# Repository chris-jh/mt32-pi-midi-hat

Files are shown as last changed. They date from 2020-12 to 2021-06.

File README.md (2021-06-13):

# mt32-pi-midi-hat
A Raspberry Pi Midi Hat for the project mt32-pi by Dale Whinham (https://github.com/dwhinham/mt32-pi).

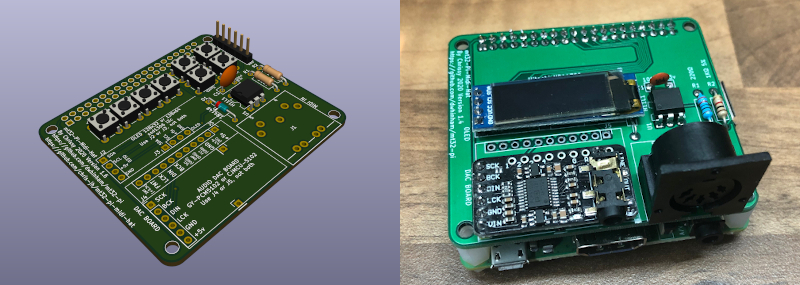
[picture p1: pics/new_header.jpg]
PCB


This PCB is designed from the schematic available from the above project.

The Gerbers have been created from the recommendations at JLCPCB.

(https://support.jlcpcb.com/article/102-kicad-515---generating-gerber-and-drill-files)

You may need to re-generate for your chosen PCB Manufacturer

Version 1.7.2 Copyright 2021 Chrissy

* Moved a trace that was too close to the mounting screw hole. Could cause a short if over tighten to expose the trace. (see https://github.com/chris-jh/mt32-pi-midi-hat/issues/3)

Version 1.7.1 Copyright 2021 Chrissy

* Moved the Midi-Din slightly

Version 1.7 Copyright 2021 Chrissy

* Fixed Silk Screen error on buttons for mt32/sf and Synth, they were opposite

Version 1.6 Copyright 2021 Chrissy

* Removed Hitachi HD44780 4 bit connection, use i2c version
* Added control pins and buttons, see (https://github.com/dwhinham/mt32-pi/wiki/Control-surface)

## Audio DAC's

I designed this Hat to accommodate 2 different PCM5102 DAC boards that are available from Amazon or eBay.

***GY-PCM5102***

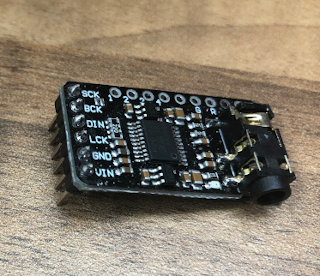
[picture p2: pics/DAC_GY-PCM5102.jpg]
DAC_GY


***CJMCU-5102***

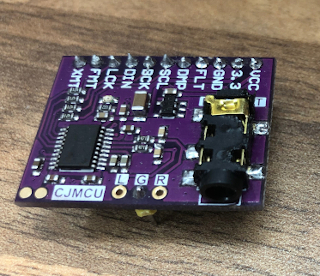
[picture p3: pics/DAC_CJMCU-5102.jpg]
DAC_CJMCU


Currently the GY-PCM5102 version seems to be the most popular on Amazon and eBay, just search for PCM5102.

## Screen's

**SSD1306 OLED**

The Hat can take either the 128x32 SSD1306 OLED, or the 128x64 SSD1306 OLED

***SSD1306 OLED 128x32***

OLED_32

***SSD1306 OLED 128x64***

OLED_64

Again both screens are available from Amazon or eBay.

The 128x64 OLED connects on the board at this position here.

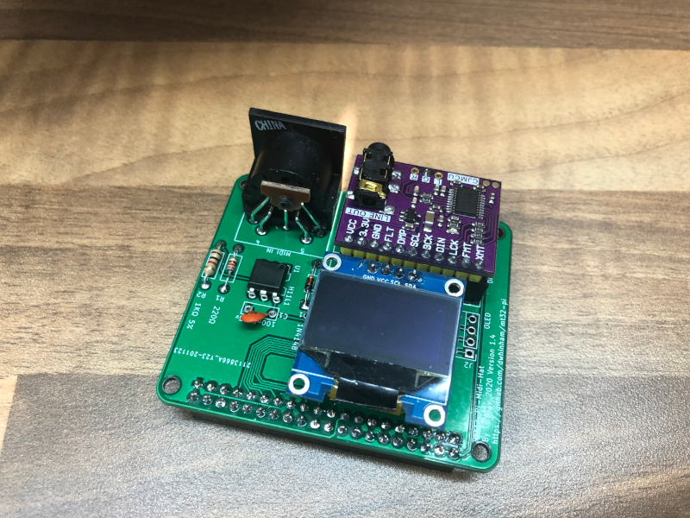
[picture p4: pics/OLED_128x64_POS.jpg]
OLED_64_POS


You will need to put some none conductive material under the OLED,<br>so it does not short agains the Pins of the Raspberry Pi.

When you buy your screen, make sure the PIN order is as follow's (left to right, looking down on the screen):-

| 1 | 2 | 3 | 4 |
|---|---|---|---|
|GND|VCC|SCL|SDA|

You can see this in the photo above.

Some SSD1306 OLED's have Pins 1 and 2 swapped, which will be bad. So please double check.

***Hitachi HD44780***

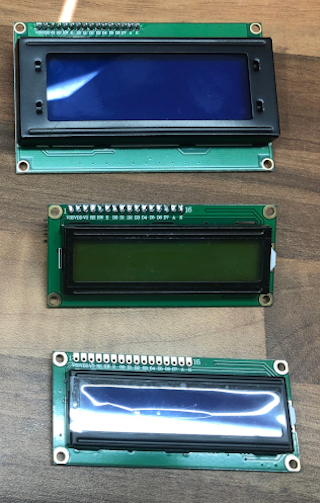
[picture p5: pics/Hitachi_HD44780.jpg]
[](pics/Hitachi_HD44780.jpg)

There are two versions of this screen, one that communicates via the i2c (like the above OLEDS) or a direct connection.

I have removed the direction connection from v1.6 to give enough room to fit the control buttons.

Use the i2c version only and you will need to connect the screen to one of the OLED connections J2 or J3 on the PCB.

The Hitachi screen can also come in different sizes, ideally you want one that is 20 characters in length and either 2 or 4 lines.

<br>

### Configuration

Please see the main mt32-pi Project (https://github.com/dwhinham/mt32-pi) on how to configure and use your screen and DAC.

### BOM

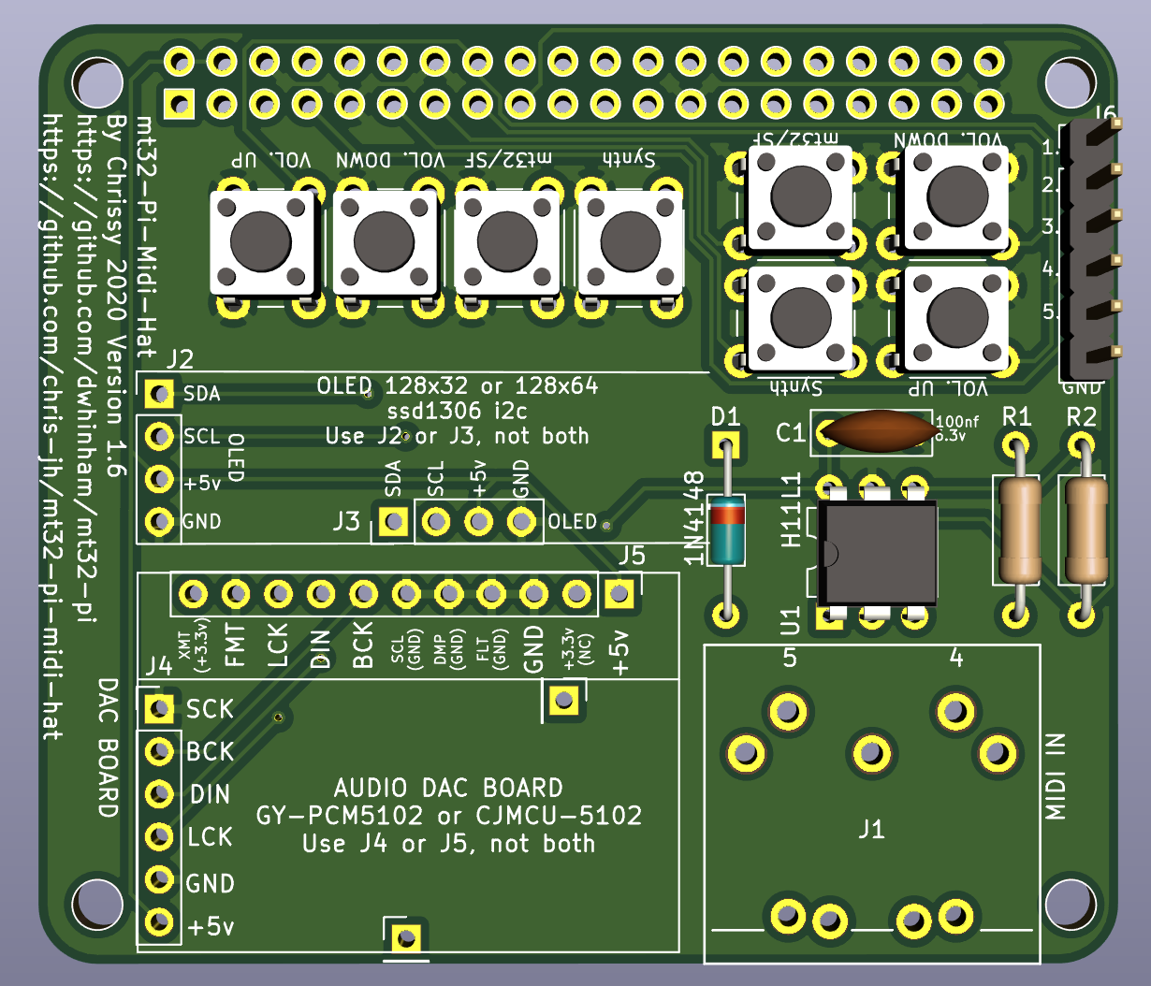
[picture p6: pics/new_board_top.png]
PCB_TOP


| Reference | Value | Quantity | URL |
|---|---|---|-----|
| C1 | 100nf | 1 | https://www.mouser.co.uk/ProductDetail/Murata-Electronics/RCER71E104K0K1H03B?qs=Ey7%2FXF42M3ci4g3t0g7SIw%3D%3D |
| R1 | 220Ω | 1 | https://www.mouser.co.uk/ProductDetail/Vishay-Beyschlag/MBB02070C2200FCT00?qs=PwR17mNzlcOWyOoLtTQfsw%3D%3D |
| R2 | 1KΩ 5% | 1 | https://www.mouser.co.uk/ProductDetail/Vishay-Dale/CCF071K00JKE36?qs=NQWA6AwZmkMdaaeOGvuguw%3D%3D |
| D1 | 1N4148 | 1 | https://www.mouser.co.uk/ProductDetail/ON-Semiconductor-Fairchild/1N4148?qs=i4Fj9T%2FoRm8RMUhj5DeFQg%3D%3D |
| U1 | H11L1 | 1 | https://www.mouser.co.uk/ProductDetail/ON-Semiconductor-Fairchild/H11L1M?qs=P36CEcFBmYxn5ViwkIckpw%3D%3D |
| J1 | DIN-5 | 1 | https://www.mouser.co.uk/ProductDetail/490-SDS-50J |
| J2 or J3 | SSD1306 OLED | 1 | Amazon or eBay |
| J4 or J5 | DAC GY-PCM5102<br>or<br>CJMCU-5102  | 1 | Amazon or eBay |
| J6 | External Button Pin Header 1x6 | 1 | Amazon or eBay |
| SW1,2,3,4 | Tact Switch 6x6mm | 4 | Amazon or eBay |
| Pi | Header| 1 | https://www.mouser.co.uk/ProductDetail/Samtec/SSQ-120-23-G-D?qs=rU5fayqh%252BE1BMVd%252BDZONqg%3D%3D |

You may want to get some general Pin Headers 2.54mm, only 1 extra pin is used to stabilise the DAC's for when pushing in the headphone jack.

[**THT Interactive BOM**][IBOMTHT1_6]

## !!!!! WARNING !!!!!

Use at your own risk. I accept no responsibility if this damages any of your equipment.

[IBOMTHT1_6]: http://htmlpreview.github.io/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

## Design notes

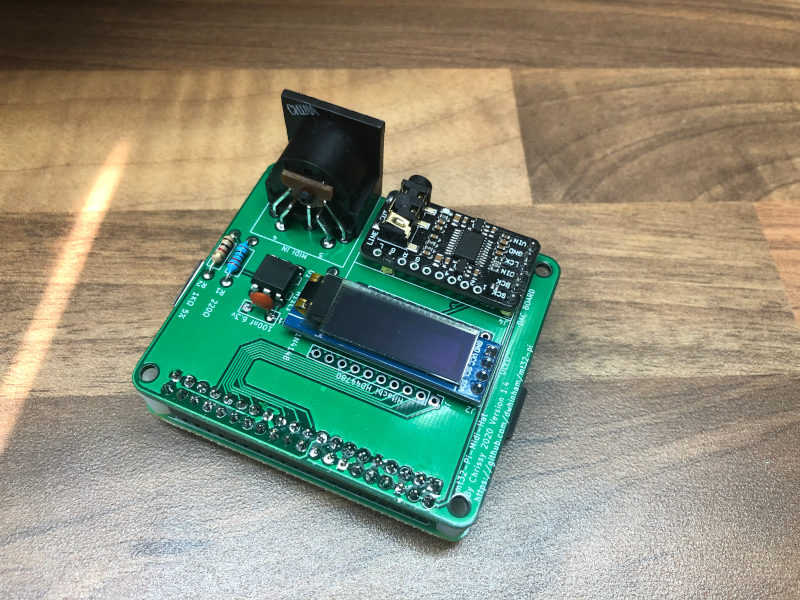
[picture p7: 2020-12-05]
pics/board_back.jpg

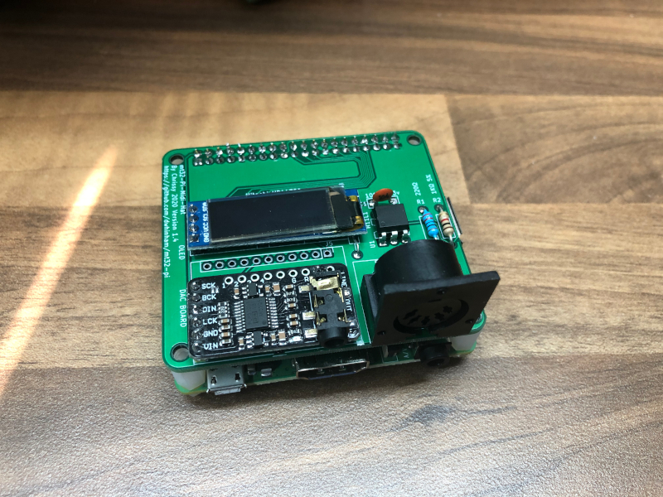
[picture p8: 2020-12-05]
pics/board_front.jpg

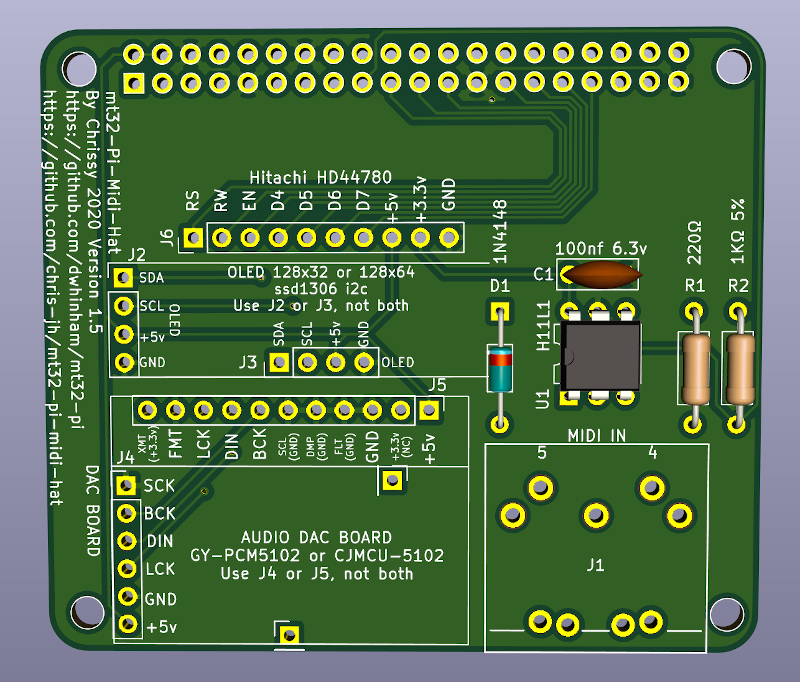
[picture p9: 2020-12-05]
pics/board_top.jpg

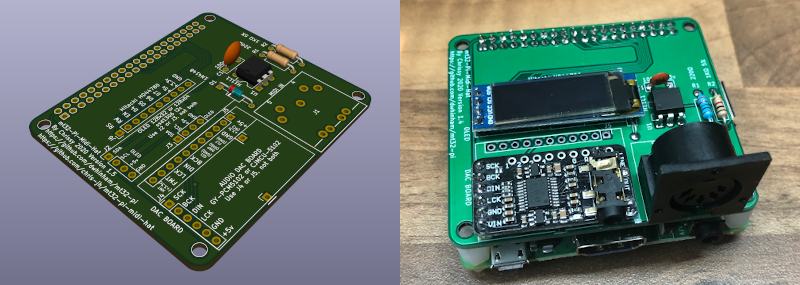
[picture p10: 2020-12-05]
pics/header.jpg

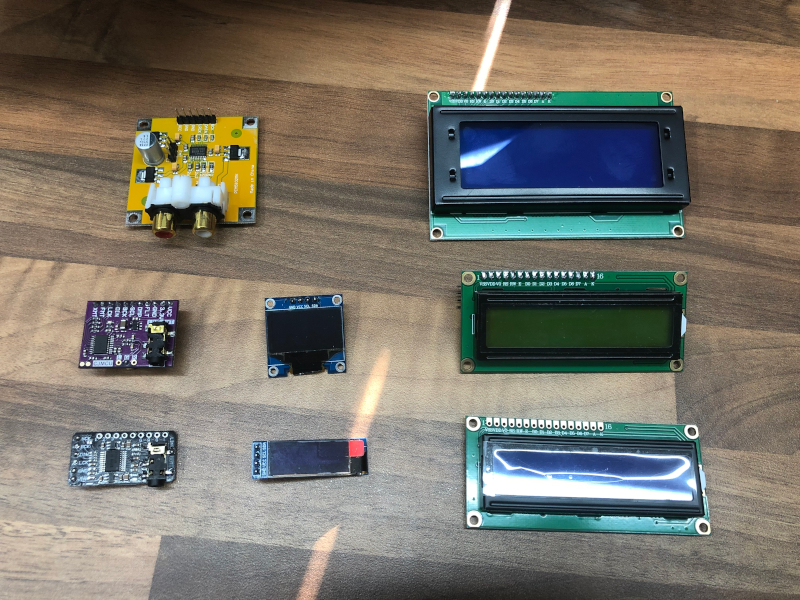
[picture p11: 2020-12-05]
pics/dacs_screens.jpg

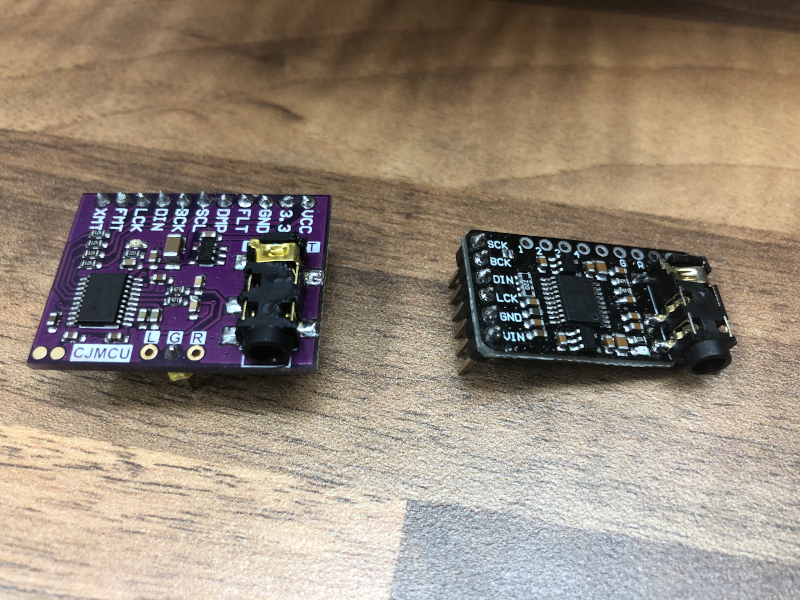
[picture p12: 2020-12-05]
pics/PM5102_DACS.jpg

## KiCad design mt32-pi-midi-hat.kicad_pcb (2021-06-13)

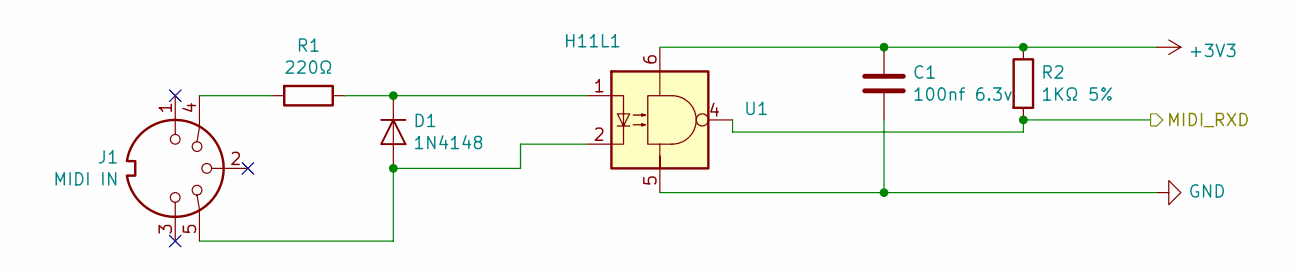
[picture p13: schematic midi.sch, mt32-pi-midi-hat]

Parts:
C1: 100nf 6.3v; C_Disc_D7.0mm_W2.5mm_P5.00mm
D1: 1N4148; D_DO-35_SOD27_P10.16mm_Horizontal
J1: MIDI IN; DIN-5-Variable
R1: 220Ω; R_Axial_DIN0207_L6.3mm_D2.5mm_P10.16mm_Horizontal
R2: 1KΩ 5%; R_Axial_DIN0207_L6.3mm_D2.5mm_P10.16mm_Horizontal
U1: H11L1; DIP-6_W7.62mm

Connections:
+3V3: C1.1, R2.1, U1.6; also elsewhere on the board
/Midi/MIDI_RXD: R2.2, U1.4; also elsewhere on the board
GND: C1.2, U1.5; also elsewhere on the board
unnamed: D1.1 (K), R1.1, U1.1
unnamed: D1.2 (A), J1.5, U1.2
unnamed: J1.4, R1.2

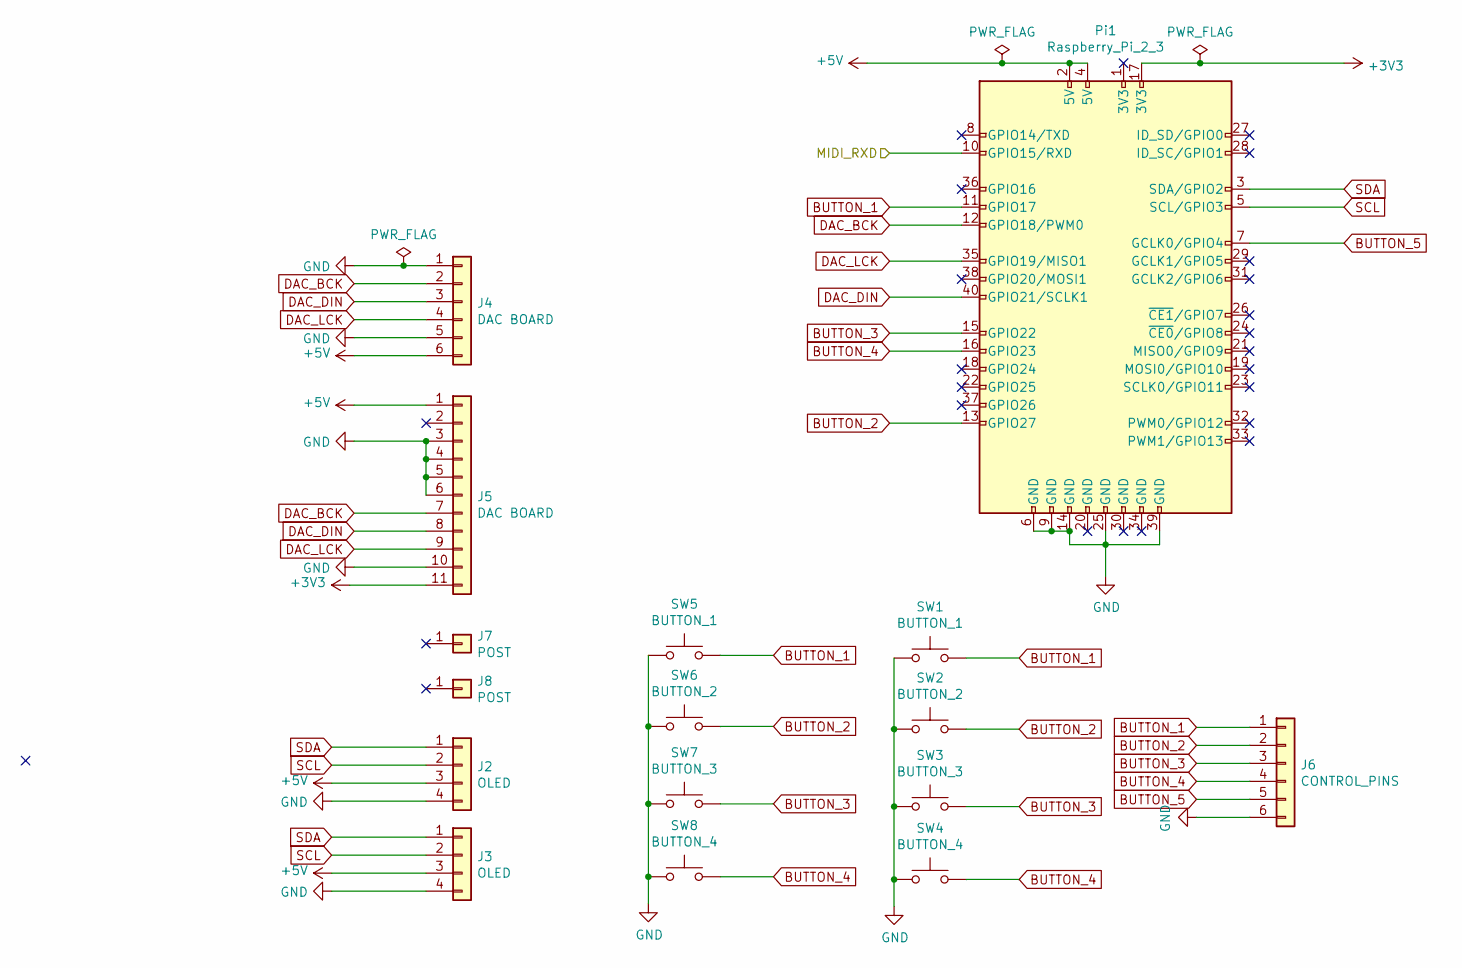
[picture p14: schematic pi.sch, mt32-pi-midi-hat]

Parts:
J2, J3: OLED; PinHeader_1x04_P2.54mm_Vertical
J4: DAC BOARD; PinHeader_1x06_P2.54mm_Vertical
J5: DAC BOARD; PinHeader_1x11_P2.54mm_Vertical
J6: CONTROL_PINS; PinHeader_1x06_P2.54mm_Vertical
J7, J8: POST; PinHeader_1x01_P2.54mm_Vertical
Pi1: Raspberry_Pi_2_3; raspberrypi_2_3
SW1, SW5: BUTTON_1; SW_PUSH_6mm_SLIM
SW2, SW6: BUTTON_2; SW_PUSH_6mm_SLIM
SW3, SW7: BUTTON_3; SW_PUSH_6mm_SLIM
SW4, SW8: BUTTON_4; SW_PUSH_6mm_SLIM

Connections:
+3V3: J5.11, Pi1.17 (3V3); also elsewhere on the board
+5V: J2.3, J3.3, J4.6, J5.1, Pi1.2 (5V), Pi1.4 (5V)
/Midi/MIDI_RXD: Pi1.10 (GPIO15/RXD); also elsewhere on the board
BUTTON_1: J6.1, Pi1.11 (GPIO17), SW1.2, SW5.2
BUTTON_2: J6.2, Pi1.13 (GPIO27), SW2.2, SW6.2
BUTTON_3: J6.3, Pi1.15 (GPIO22), SW3.2, SW7.2
BUTTON_4: J6.4, Pi1.16 (GPIO23), SW4.2, SW8.2
BUTTON_5: J6.5, Pi1.7 (GCLK0/GPIO4)
DAC_BCK: J4.2, J5.7, Pi1.12 (GPIO18/PWM0)
DAC_DIN: J4.3, J5.8, Pi1.40 (GPIO21/SCLK1)
DAC_LCK: J4.4, J5.9, Pi1.35 (GPIO19/MISO1)
GND: J2.4, J3.4, J4.1, J4.5, J5.3, J5.4, J5.5, J5.6, J5.10, J6.6, Pi1.6 (GND), Pi1.9 (GND), Pi1.14 (GND), Pi1.25 (GND), Pi1.39 (GND), SW1.1, SW2.1, SW3.1, SW4.1, SW5.1, SW6.1, SW7.1, SW8.1; also elsewhere on the board
SCL: J2.2, J3.2, Pi1.5 (SCL/GPIO3)
SDA: J2.1, J3.1, Pi1.3 (SDA/GPIO2)

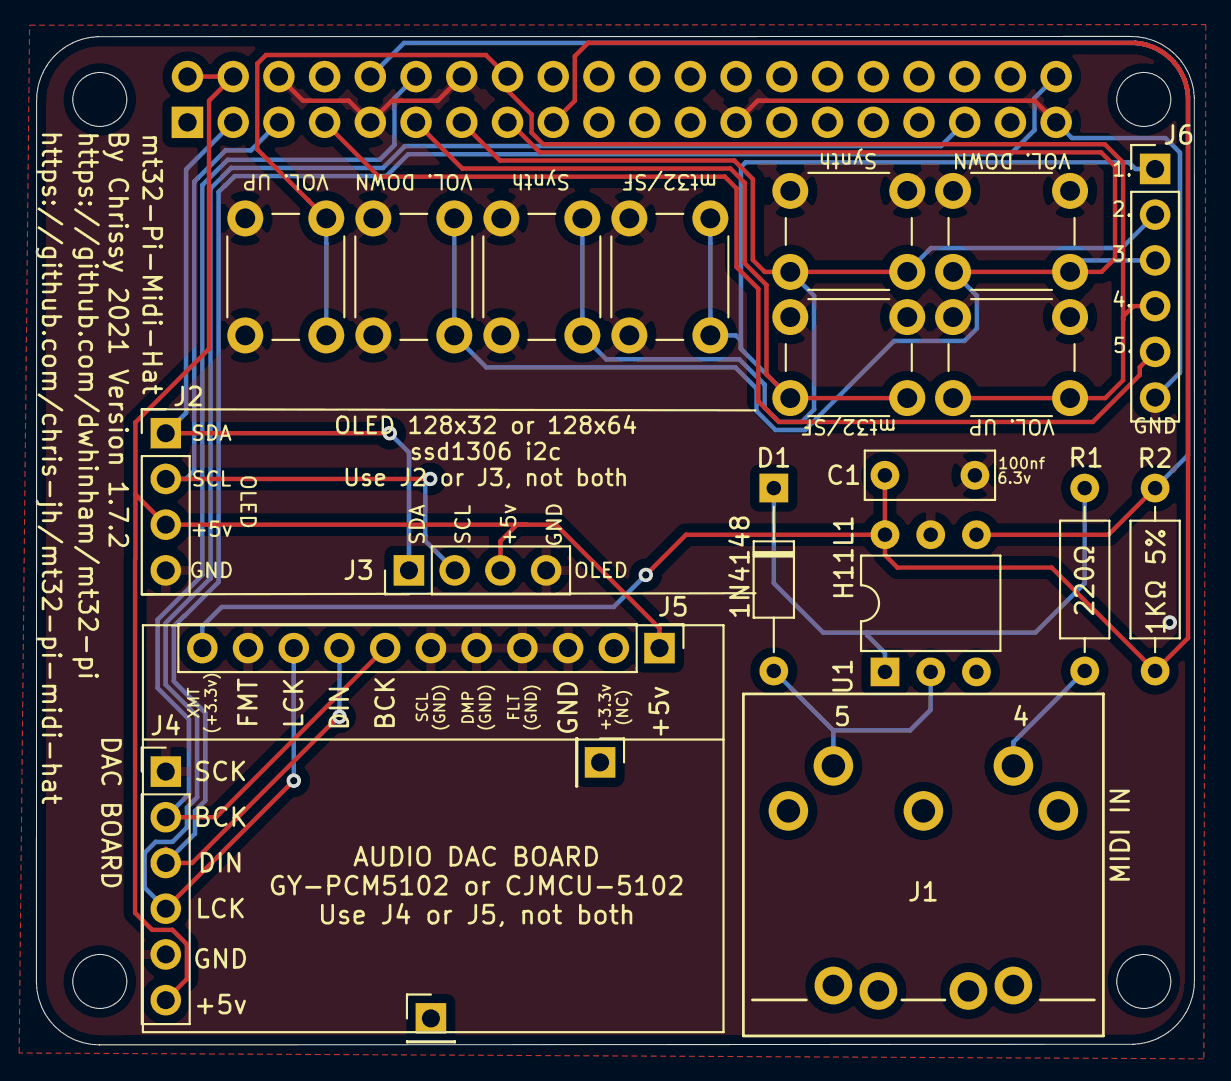
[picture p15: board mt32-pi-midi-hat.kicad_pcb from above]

Board: 2 copper layers, 64.3 x 56.0 mm, 22 parts (0 on the bottom side), 17 nets.

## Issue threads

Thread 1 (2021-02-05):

OSHPark shows board bottom as white

leolobato, 2021-02-05:
I'm not experienced at all with producing/ordering PCBs but am looking forward to assembling this project.

I've tried uploading the Gerbers_v1_7.zip file to OSHPark and they showed an issue at the board bottom (see attached).

Is this something that is easily fixable?

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

chris-jh, 2021-02-05:
the gerbers are made to JLCPCB Specification, so maybe this is the issue ?

I think you will need to use KiCad to make new Gerbers to OSHParks Specifications, or order from JLCPCB

leolobato, 2021-02-05:
Thank you! I'll check JLCPCB.

Closed 2021-02-05.

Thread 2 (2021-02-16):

1.7 on oshpark bottom white?

b0rnwr0ng, 2021-02-16:
Is the template that is uploaded correct?  Seems to render incorrectly

b0rnwr0ng, 2021-02-18:
Reading through everything I see it was made with recommends with jlxpcb.  I was having issues there so went another route.  Will let you know how they turn out, ordered from another site as well.

Also got 1.5 working no issues

chris-jh, 2021-02-18:
I think it may have been the Midi-Din connector being right on the edge so i have moved it and produced another gerber.zip.

b0rnwr0ng, 2021-02-18:
That worked!  I'll post how the 1.7 came out if I'm able to.

b0rnwr0ng, 2021-03-01:
I didn't realize there was a closed issue already on this.  I got back the 1.7 boards and seem ok, although hace a ton 1.7.1s on the way back

Closed 2021-02-18.

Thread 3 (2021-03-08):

Tracer is very close to mounting screw.

skadarnold, 2021-03-08:
Minor issue where the tracer next to this GPIO pin can be exposed when tightening mounting screws to raspberry pi case. Recommended using a washer or nylon screws when using version 1.7 of this hat. Causes the raspberry pi to short when turning on. Did not cause any damage from what I can tell as removing the screw allowed everything to work as it should. It is also worth mentioning that I tightened as normal, and did not necessarily over tighten this screw.

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

chris-jh, 2021-06-13:
I will move it, when i get around, good call. Although i used nylon screws, so never noticed.

chris-jh, 2021-06-13:
fixed

Closed 2021-06-13.

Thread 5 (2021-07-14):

J6 Pinout

appiah4, 2021-07-14:
Hi building one of these for use as a hat.  I will use on board microswitches for now but hope to design a case with external buttons eventually.  J6 seems to be for this purpose, but I can't seem to find the pinout and how to connect external buttons to the device in the documentation.  Can you assist? Thanks.

doccaz, 2022-04-15:
I just assembled mine and was also wondering the same thing. Is J6 a breakout for the switches, or is it for connecting to the user port of a MiSTer FPGA?

chris-jh, 2022-08-03:
Sorry been a while, been really busy with work.

Yeah the J6 is just a break out of the buttons, incase you want to put in case like i did.

My board was designed before the MiSTer connection, i thought about adding it. but i don't think there is a need as there are other boards that are better suited to MiSTer.

DOSSound, 2024-09-02:
Hello... sorry to bother you... could you tell me the Pinout of the J6 connector? I intend to use an Encoder and 2 buttons, but I don't know which pins to connect it to.
And also, could you tell me if you use a Case for the MT32 pi and share the STL with me... Please
Thank you!!!

doccaz, 2024-09-07:
> Hello... sorry to bother you... could you tell me the Pinout of the J6 connector? I intend to use an Encoder and 2 buttons, but I don't know which pins to connect it to. And also, could you tell me if you use a Case for the MT32 pi and share the STL with me... Please Thank you!!!

Actually I just pinned it out with a multimeter, so it's:

1 - MT32/Soundfont
2 - Synth
3 - Vol Down
4 - Vol Up
5 - not connected (I guess it was for the encoder button that wasn´t  implemented?)
6 - Ground

I haven't used mine with a case, I ended up building some MT32Pi hats for the MiSTer since that was what I was looking for at the time I asked this. It's not my project, but I guess one could be made that holds both the Pi and the Hat. If I do one, I'll post it at https://www.thingiverse.com/docca/designs.

DOSSound, 2024-09-09:
Thank you!!!
How could I put a Rotary Encoder on it?

El vie, 6 sept 2024 a las 23:42, Erico Mendonca ***@***.***>)
escribió:

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

doccaz, 2024-09-09:
> Thank you!!! How could I put a Rotary Encoder on it?

Just follow this wiki: https://github.com/dwhinham/mt32-pi/wiki/Control-surface

You need to define a simple_encoder scheme, and connect the encoder to the mentioned pins (increase/decrease volume as encoder CLK or DAT).

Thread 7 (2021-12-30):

Has anybody designed any 3D printable cases for this?

sofakng, 2021-12-30:
Has anybody designed any 3D printable cases for this?

luciust, 2022-04-10:
I'm probably going to -the minimal version for start. Will let you know.

GrumpyModeler, 2022-04-10:
I will once I have build my hat. I will probably try to imitate the MT-32 design somehow.

I make a lot of 3D printable things for retro computers: https://cults3d.com/en/users/tahustvedt/creations

luciust, 2022-04-10:
I've soldered one extra: https://www.youtube.com/watch?v=6UznlM8iv-Y

GrumpyModeler, 2022-04-10:
I've ordered the parts I'm missing and will CNC-mill the PCB myself. :)

steswart, 2024-10-14:
So, did anyone design one please?

tgmaxx, 2025-01-19:
> So, did anyone design one please?

 I have the same question.

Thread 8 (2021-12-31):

Why are there two sets of buttons?

sofakng, 2021-12-31:
Why are there two sets of buttons?

Am I correct that if you install the 128x32 LCD (long horizontal) then you should not install the 4 square button layout in the corner of the board?  (the LCD almost fits but hits the corner of the Synth button)

Similarly, if you install the 128x64 LCD that you should not install the horizontal row of buttons?  (it looks like the LCD would sit on top of the buttons if I understand the layout correctly which seems obviously wrong)

doccaz, 2022-04-15:
I just assembled mine with a 128x32 OLED and only after assembling everything I noticed that the buttons were duplicated :)

The 128x32 OLED is so thin that it doesn't hit any of the buttons. But adding the 128x64 OLED surely will hit the horizontal row.
Maybe would be useful to add some lettering to the board along the lines of "if you use the 128x64 OLED, don't install these switches".

chris-jh, 2022-08-03:
Correct, incase you use the different oled screen sizes which have different locations for connecting to the board.

Closed 2022-08-03.

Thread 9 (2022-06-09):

LCD VCC-GND swapped

shaeon, 2022-06-09:
Hello,

 I'm order some pcbs but I need swap VCC and GND from LCD J3.

I left you a screen, in the first photo you can check is swapped that is like now are coming this lcd. In the second photo its like you did.

We had the same problem in other project and we fix it with soldering point like that:

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

Here is the original project -> https://github.com/somhi/MIDI_I2S_SBC_Pmod_Edge_Interface

Great job!

Best Regards,
Shaeon.

chris-jh, 2022-08-03:
Thanks, yeah been meaning to add something to be able to change it. Just been really really busy with work.

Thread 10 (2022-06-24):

Can this hat be used with a MISTER FPGA?

vdorza, 2022-06-24:
Hello!
I´ve built it and it works marvelous with my 486 PC and ORPHEUS sound card, but i would like to know if there is a way to connect it to the MISTER FPGA (as other hats i´ve seen have like a usb port to do so)

Thnks!

chris-jh, 2022-08-03:
My board was made before the MiSTer stuff was added. You'd have to manually solder a USB3 cable to the correct pins on the Pi i think. Not really looked, only glanced at the documentation.

https://github.com/dwhinham/mt32-pi/wiki/MiSTer-FPGA%3A-Interface-pinout

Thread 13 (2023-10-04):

Raspberry pi 3A+ compatibility issue

elterwater, 2023-10-04:
Hi,
I realise that this strictly speaking an mt32-pi issue and not an mt32-pi-midi-hat issue, but I have run into this problem having started to build the this midi-hat today. Apologies for raising this here as I can't find any way of raising it on dwhinham's repository as it's locked out to collaborators only.
I have bought 2 fresh Raspberry Pi 3A+ from ThePiHut and my PCBs have finally arrived from JLCPCB.
I was not able to boot the Pi 3A+ boards with the latest few releases of mt32-pi (e.g. mt32-pi-0.13.1.zip from the releases list of dwhinham's repository). It just sits and blinks 4 long green flashes then 7 short green flashes.
I did eventually get one of his kernel-hdmi releases onto a pi4 board I have and it boots without an issue and I can see the display on my ssd1306.

I eventually tracked it down to start_cd.elf in the mt32-pi-0.13.1.zip distribution. I have replaced this with the official raspbery-pi firmware-master version and now it boots ok my Pi 3A+ boards as well, everything works so far.

Maybe something has been updated on the most recent Pi 3A+ boards supplied to ThePiHut which causes this incompatibility?

celso, 2025-05-18:
I had this exact same problem and reading your solutions solved it, thank you.

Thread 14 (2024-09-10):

PCBWay

DOSSound, 2024-09-10:
Hello... good morning!!
I have tried to upload the files for the PCB printout but the pages I have tried on have failed to recognize them.
Will you have the GERBER files or a .ZIP that can recognize the print page?
Thank you!

Closed 2024-09-10.

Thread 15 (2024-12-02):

Reset Sound

DOSSound, 2024-12-02:
Hello.. I have completed the assembly of this device...
When testing it, I noticed that every so often (randomly) the audio cuts off (something similar to an audio reset).
I'm using it with a keyboard connected by MIDI cable and it sounds SUPER... but every once in a while it's like I stop pressing the keys the way the audio cuts out...
Do you know if there is any reason for this?
I have tried changing values   for the number of notes, sampling frequency and things like that... I have not touched the Baud Rate and I have WIFI+usb+ftp enabled.
The sound sources I'm using range from less than 1mb to a couple hundred (I don't think this is the cause of the problem)

Greetings!

chris-jh, 2024-12-05:
Hi, i am unsure.

You might need to refer to the mt32Pi project as it was based on the schematic provided by Dale (https://github.com/dwhinham/mt32-pi/wiki/GPIO-MIDI-interface)

Have you search the issues section on the main mt32-pi project page for anything similar ?

I am unfamiliar with the software side, my pi hat is still running a very old version 😂

Unless faulty DAC ?

DOSSound, 2024-12-11:
Thank you! In the first instance, I assume that it is a problem with my keyboard since I have tested your implementation with the Bulky Midi Play Project (which is a .mid file player that needs an external device that has the synthesizer) and the problem mentioned above did not occur. .
I haven't been able to get another keyboard or any other way to check this...
When I have the confirmation I'll tell you...
Greetings!

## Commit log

2020-12-05 mt32-pi-midi-hat
    First commit
    [dac.sch, midi.sch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]
2020-12-05 Update README.md
    Extra note on BOM
2020-12-05 Update README.md
    Updated SSD1306 Oled Pin 1 and 2 swap note
2020-12-09 Update README.md
    Wrong Pin Header, updated to correct one
2021-01-03 Version 1.6
    1. Removed Hitachi 4bit version
    2. Added new buttons from version 0.8 of the mt32-pi project
    [midi.sch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]
2021-01-03 fix wrong date on back
    fixed wrong version and date on back of pcb
    slight adjustment of 128x64 oled pins
    [mt32-pi-midi-hat-B_Cu.gbr, mt32-pi-midi-hat-B_Mask.gbr, mt32-pi-midi-hat-B_SilkS.gbr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]
2021-01-16 Version 1.7
    Fixed Silk Screen error for buttons mt32/SF and Synth
    [mt32-pi-midi-hat-B_Cu.gbr, mt32-pi-midi-hat-B_Mask.gbr, mt32-pi-midi-hat-B_SilkS.gbr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]
2021-01-16 Update README.md
    added tact switch to bom list
2021-02-05 Update README.md
    Update about gerbers
2021-02-05 Update README.md
    Moved gerber info
2021-02-18 V1.7.1
    Moved the Midi Din Slightly, may have caused issues with OSHPark.
    [mt32-pi-midi-hat-B_Cu.gbr, mt32-pi-midi-hat-B_Mask.gbr, mt32-pi-midi-hat-B_SilkS.gbr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]
2021-06-13 Version 1.7.2
    moved a trace too near the mounting screw hole
    [mt32-pi-midi-hat-B_Cu.gbr, mt32-pi-midi-hat-B_Mask.gbr, mt32-pi-midi-hat-B_SilkS.gbr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]
